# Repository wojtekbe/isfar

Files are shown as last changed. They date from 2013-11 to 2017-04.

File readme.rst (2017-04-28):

Isfar - a Hybrid-ROV underwater robot
=====================================

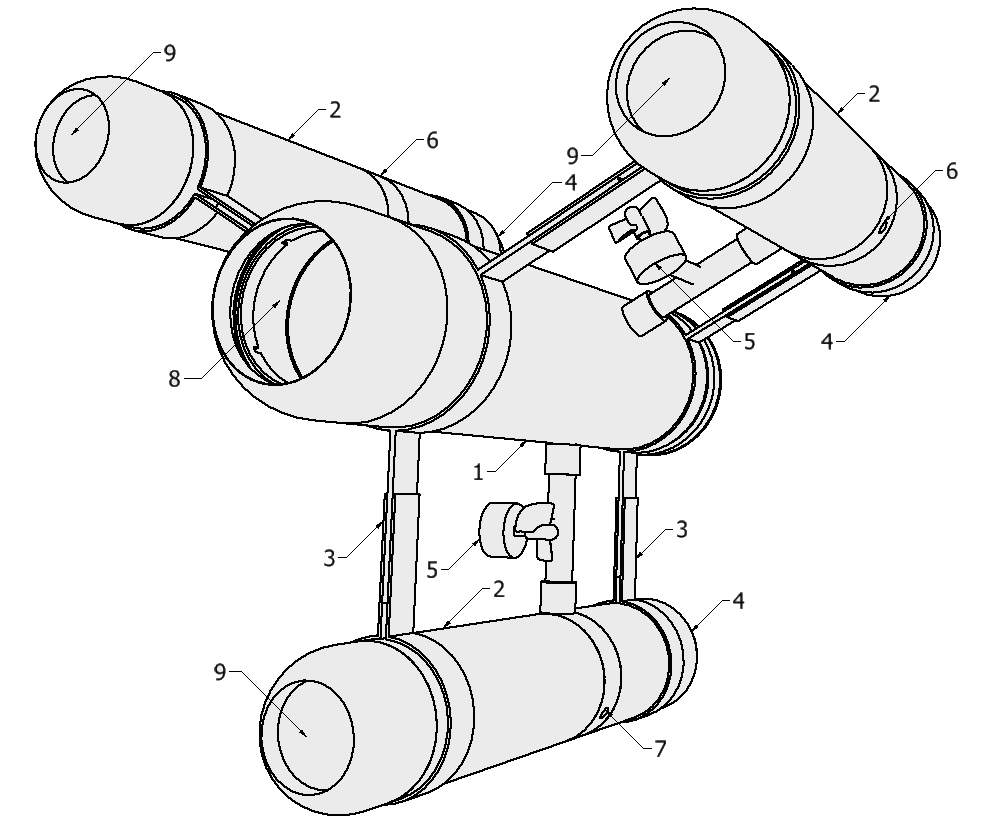
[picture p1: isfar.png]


+---+-------------+---+--------------------+---+----------------------------------+
| 1 | main hull   | 4 | main drive         | 7 | environmnental measurements unit |
+---+-------------+---+--------------------+---+----------------------------------+
| 2 | side hull   | 5 | maneouvering drive | 8 | onboard vision system            |
+---+-------------+---+--------------------+---+----------------------------------+
| 3 | steel frame | 6 | buoyancy drive     | 9 | LED lighting                     |
+---+-------------+---+--------------------+---+----------------------------------+

Boards: mainboard
-----------------

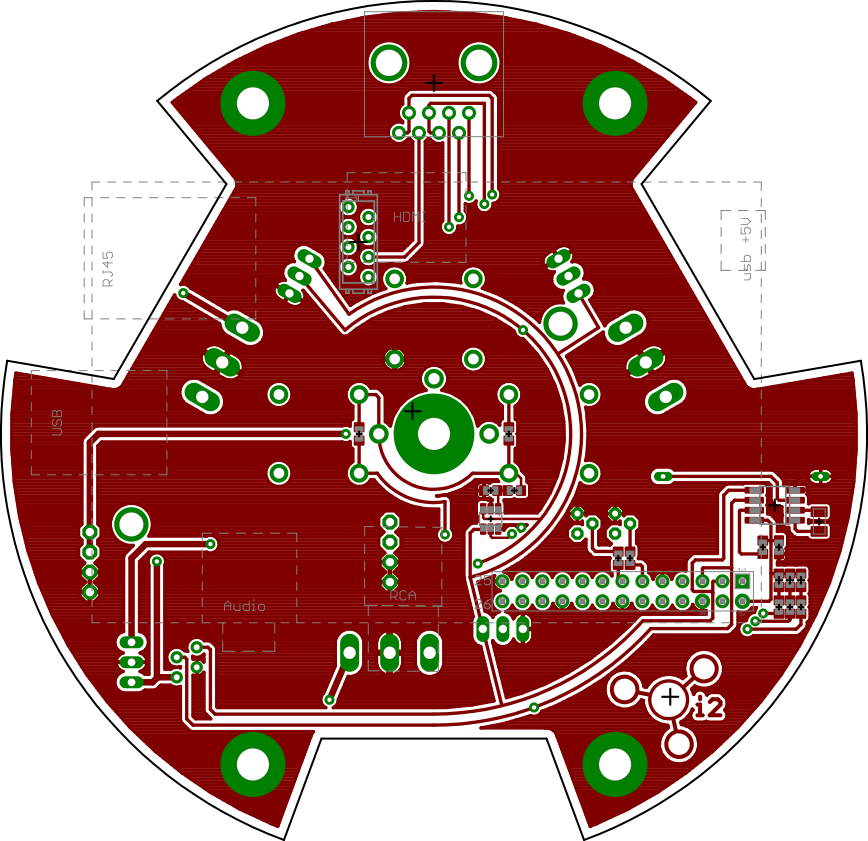
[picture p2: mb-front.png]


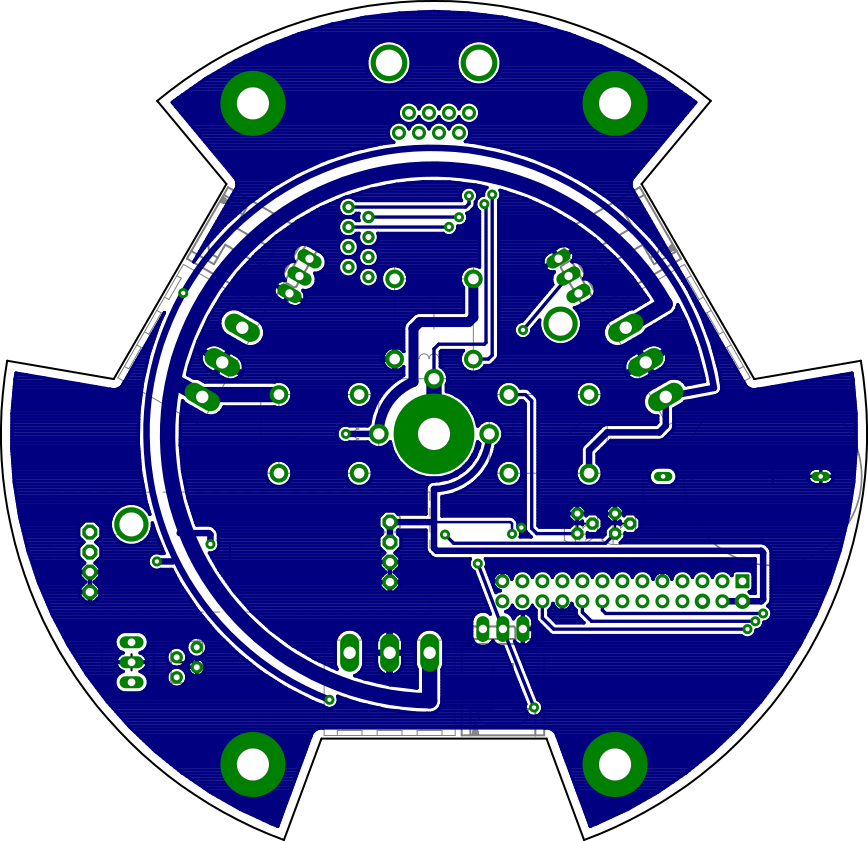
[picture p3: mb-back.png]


Boards: sidedriver
------------------

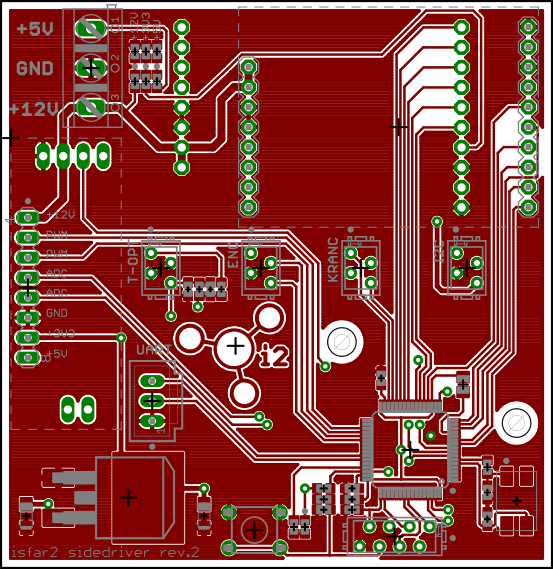
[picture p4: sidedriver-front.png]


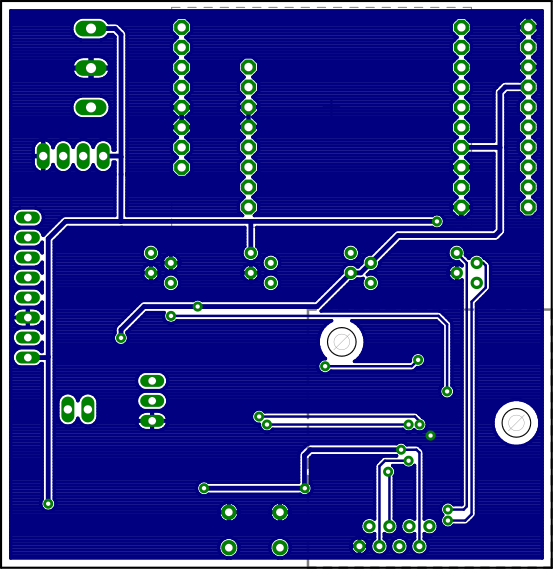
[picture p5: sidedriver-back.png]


Boards: trinocular/rpicam
-------------------------

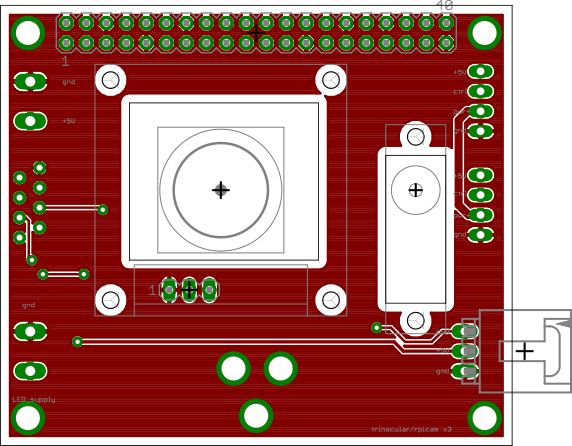
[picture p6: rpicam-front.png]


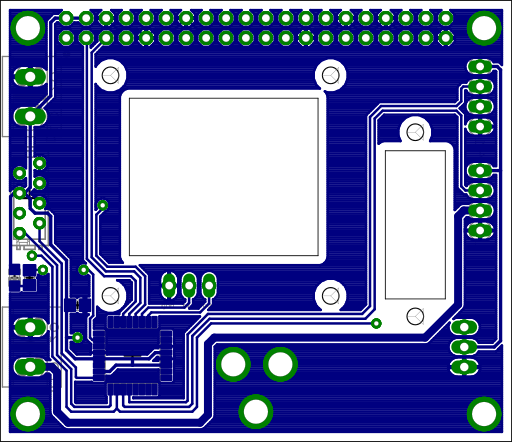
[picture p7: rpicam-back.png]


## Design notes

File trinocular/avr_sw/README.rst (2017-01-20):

SERVO:
the default i2c address is 0x0a, the angle reg is 0x01, the board is connected to i2c1 so

 .. code:: bash

 i2cset -y 1 0x0a 0x01 <angle>

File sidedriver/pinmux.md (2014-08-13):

Motor driver
====
| Name | Pin  |  Func. |
| --- | ---- | --- |
| M1_ENA  | PC3  | |
| M1_ENB  | PA3  | |
| M1_INA  | PC2  | |
| M1_INB  | PA4  | |
| M1_PWM  | PA1  | TIM2_CH2  |
| M1_CS | PA2  | ADCx_IN2  |
| ENC1 | PC6  | TIM8_CH1  |
| ENC2 | PC7  | TIM8_CH2  |

TIM4 -> calculate speed isr 
TIM5 -> PID isr

Tank driver
====
| Name | Pin  |  Func. |
| --- | ---- | --- |
| M2_ENA  | PB1  | |
| M2_ENB  | PA6  | |
| M2_INA  | PB2  | |
| M2_INB  | PA5  | |
| M2_PWM  | PB0  | TIM1_CH2N |
| M2_CS | PA7  | ADCx_IN7  |
| TRANS	  | PB6  | TIM3_CH3* |
| MIN | PB10 | |
| MAX | PB11 | |

* counting in isr

LED driver
====
| Name | Pin  |  Func. |
| --- | ---- | --- |
| LED_PWM | PC9  | TIM3_CH4  |
| SM1_PWM | PA0  | TIM5_CH1  |
| SM2_PWM | PA1  | TIM5_CH2  |

External IO
===
| Name | Pin  |  Func. |
| --- | ---- | --- |
| G_ADC1  | PC0  | ADC3_IN10 |
| G_ADC2  | PC1  | ADCx_IN11 |

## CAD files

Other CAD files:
mainb/i2-mainb-dim.dwg

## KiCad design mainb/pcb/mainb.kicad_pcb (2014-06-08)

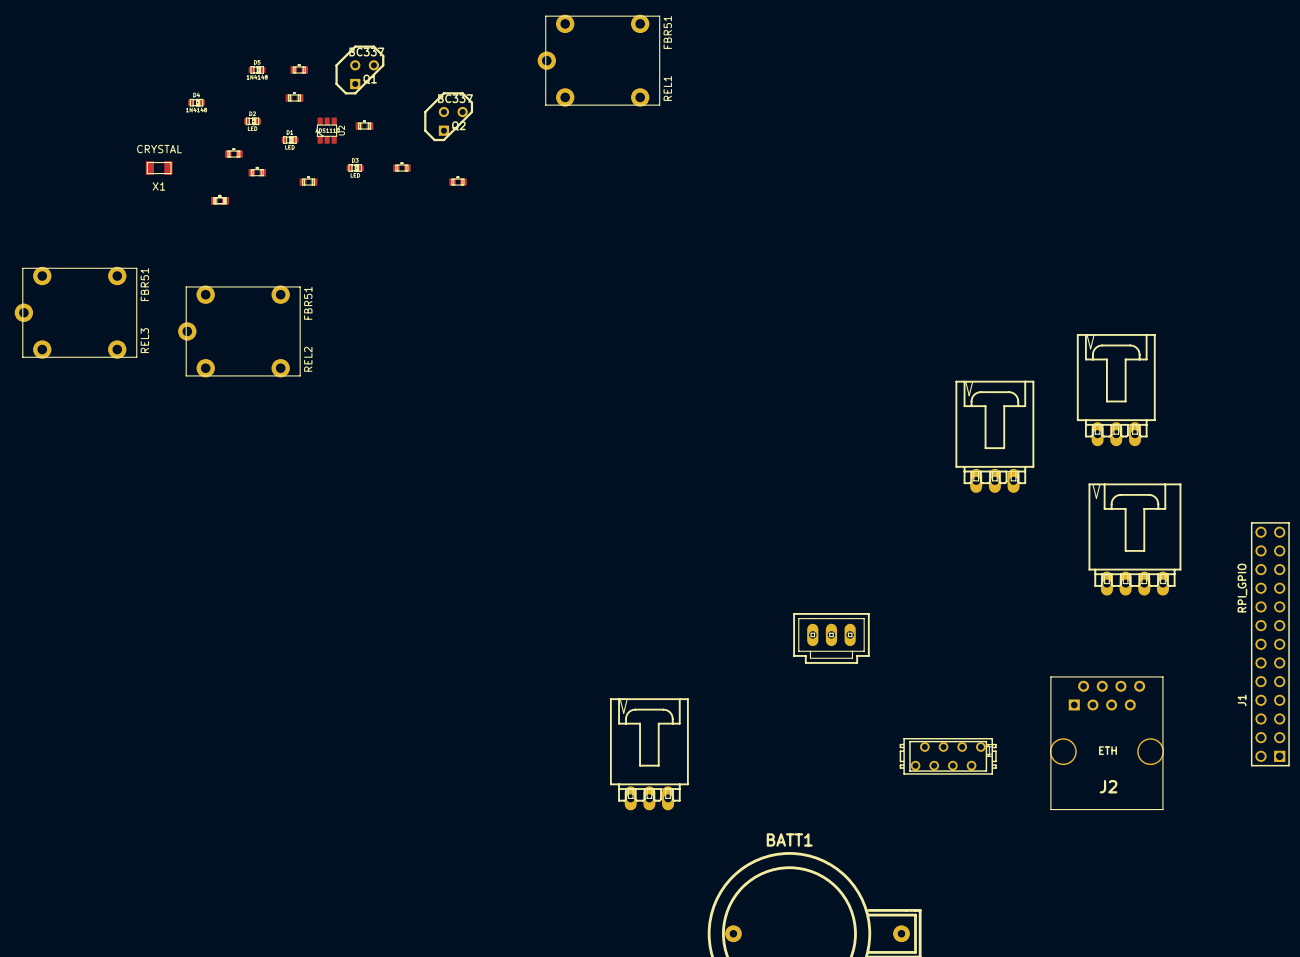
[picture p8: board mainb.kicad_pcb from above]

Board: 2 copper layers, 31 parts (0 on the bottom side), 27 nets, no tracks yet.

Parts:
BATT1: CR2303; CR2032H
C1, C2: 100n; c_0603
D1, D2, D3: LED; LED-0603
D4, D5: 1N4148; LED-0603
ETH->RPI1: CONN_8; con-amp-micromatch-MICROMATCH-8
J1: RPI_GPIO; pin_array_13x2
J2: ETH; RJ45_8
J3: I2C; WZ04R
J4, J5, J6: I2C; WZ03R
J11: UART; WZ03S
Q1, Q2: BC337; TO92-CBE
R1, R2, R6: ??; c_0603
R4, R5: R; c_0603
R7, R8, R9: 500; c_0603
REL1, REL2, REL3: FBR51
U2: ADS1110; SOT23_6
X1: CRYSTAL; CFPX-217

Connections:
+5C: J3.4, REL1.3
+5V: C1.2, C2.1, D4.2, J1.2, J1.4, R6.1, REL1.1, REL1.2, U2.5
+12V: R1.1, REL2.3
/+3V3: J1.1, R7.2, R8.2, R9.2
/LED1: D1.2, J1.22
/LED2: D2.2, J1.18
/LED3: D3.2, J1.16
/RX: J1.10, J11.2
/RX+: ETH->RPI1.4, J2.3
/RX-: ETH->RPI1.6, J2.6
/TX: J1.8, J11.3
/TX+: ETH->RPI1.1, J2.1
/TX-: ETH->RPI1.3, J2.2
AKU+: REL3.1, REL3.2
unnamed: D5.1, REL2.5
unnamed: D4.1, REL1.5
unnamed: R1.2, R2.1, U2.1
unnamed: D1.1, R9.1
unnamed: D2.1, R8.1
unnamed: D3.1, R7.1
unnamed: D5.2, REL2.1, REL2.2, REL3.3
PoE+: J2.4, J2.5, REL3.5
PoE-: BATT1.2, C1.1, C2.2, J1.6, J1.9, J1.14, J1.20, J1.25, J2.7, J2.8, J3.3, J4.3, J5.3, J6.3, J11.1, R2.2, U2.2, U2.6
REL#1: J1.11, R5.1
REL#2: J1.13, R4.1
SCL: J1.5, J3.2, J4.2, J5.2, J6.2, U2.3
SDA: J1.3, J3.1, J4.1, J5.1, J6.1, U2.4

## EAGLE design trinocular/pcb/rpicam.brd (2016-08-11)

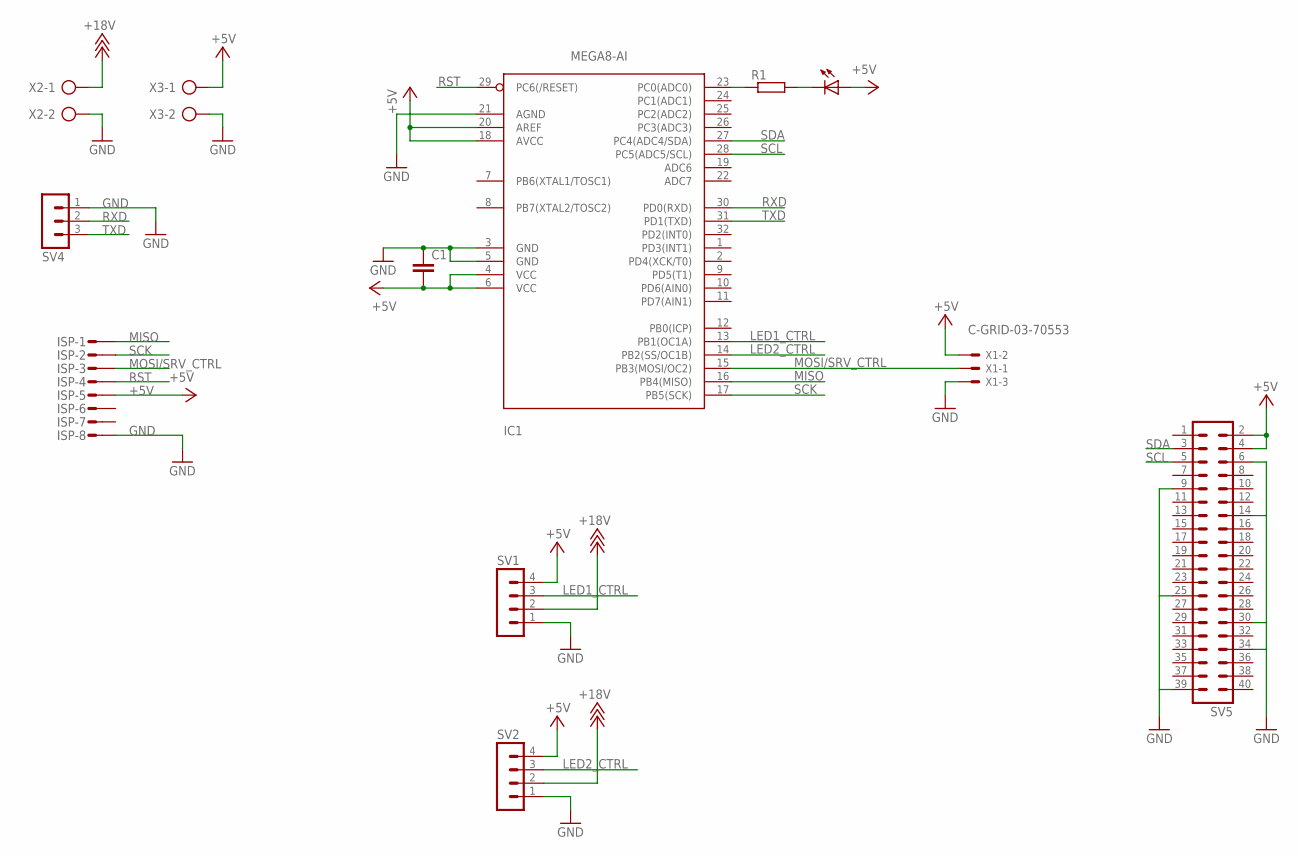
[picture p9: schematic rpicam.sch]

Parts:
C1: C-EUC0805; C0805
IC1: MEGA8-AI; TQFP32-08
ISP: MICROMATCH-8
LED1: LEDCHIP-LED0805; CHIP-LED0805
R1: R-EU_R0805; R0805
SV1, SV2: MA04-1
SV4: MA03-1
SV5: MA20-2
X1: C-GRID-03-70553; 70553-03
X2, X3: AK500/2

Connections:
+5V: C1.2, IC1.4 (VCC), IC1.6 (VCC), IC1.18 (AVCC), IC1.20 (AREF), ISP.5, LED1.A, SV1.4, SV2.4, SV5.2, SV5.4, X1.2, X3.1
+18V: SV1.2, SV2.2, X2.1
GND: C1.1, IC1.3 (GND), IC1.5 (GND), IC1.21 (AGND), ISP.8, SV1.1, SV2.1, SV4.1, SV5.6, SV5.9, SV5.14, SV5.25, SV5.30, SV5.34, SV5.39, X1.3, X2.2, X3.2
LED1_CTRL: IC1.13 (PB1(OC1A)), SV1.3
LED2_CTRL: IC1.14 (PB2(SS/OC1B)), SV2.3
MISO: IC1.16 (PB4(MISO)), ISP.1
MOSI/SRV_CTRL: IC1.15 (PB3(MOSI/OC2)), ISP.3, X1.1
unnamed: LED1.C, R1.2
unnamed: IC1.23 (PC0(ADC0)), R1.1
RST: IC1.29 (PC6(/RESET)), ISP.4
RXD: IC1.30 (PD0(RXD)), SV4.2
SCK: IC1.17 (PB5(SCK)), ISP.2
SCL: IC1.28 (PC5(ADC5/SCL)), SV5.5
SDA: IC1.27 (PC4(ADC4/SDA)), SV5.3
TXD: IC1.31 (PD1(TXD)), SV4.3

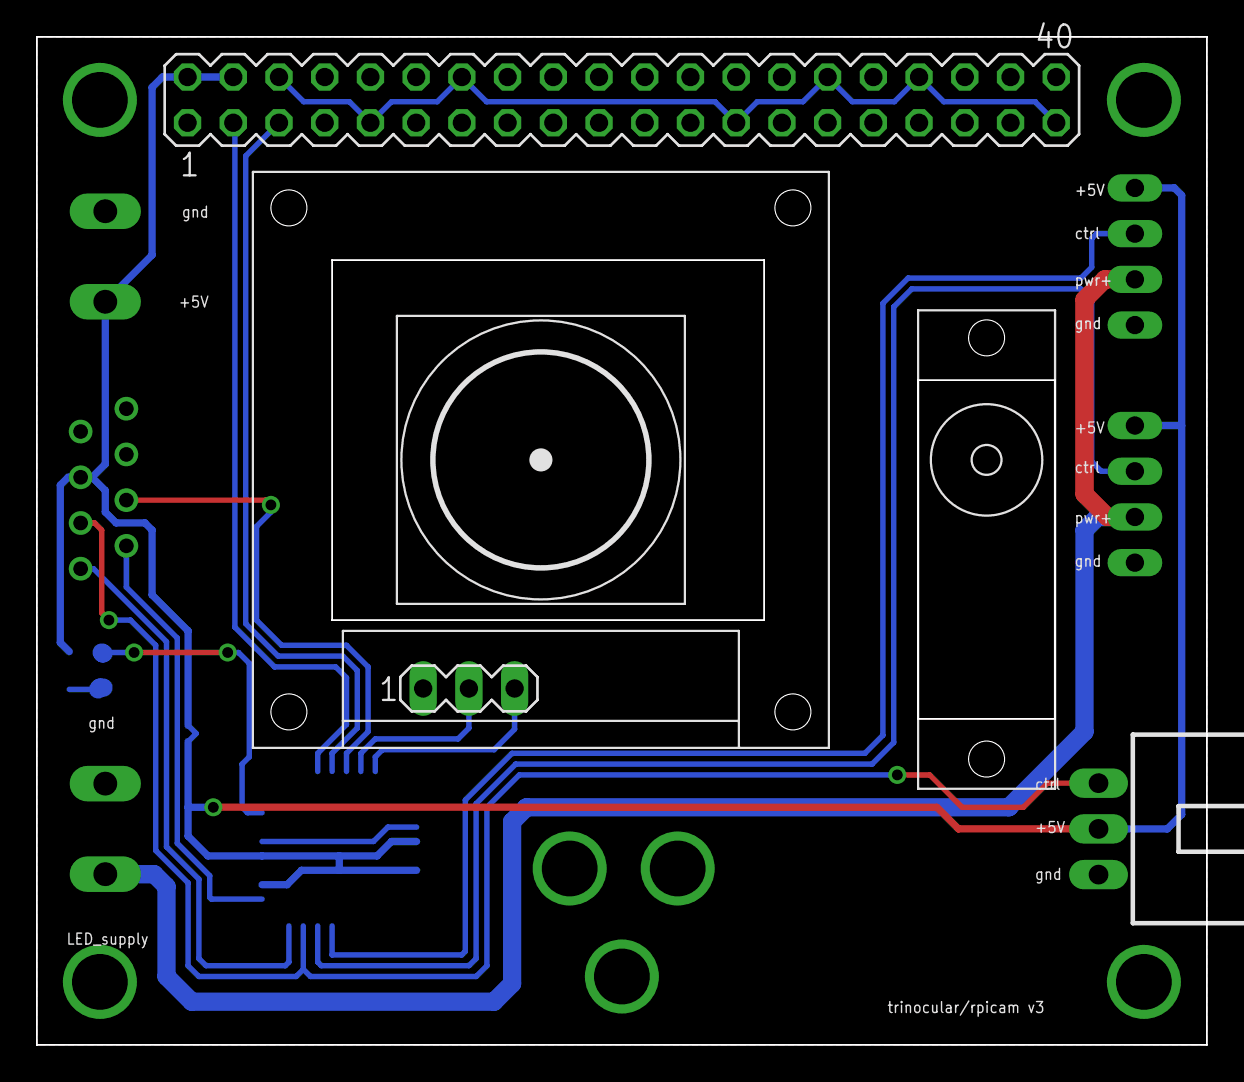
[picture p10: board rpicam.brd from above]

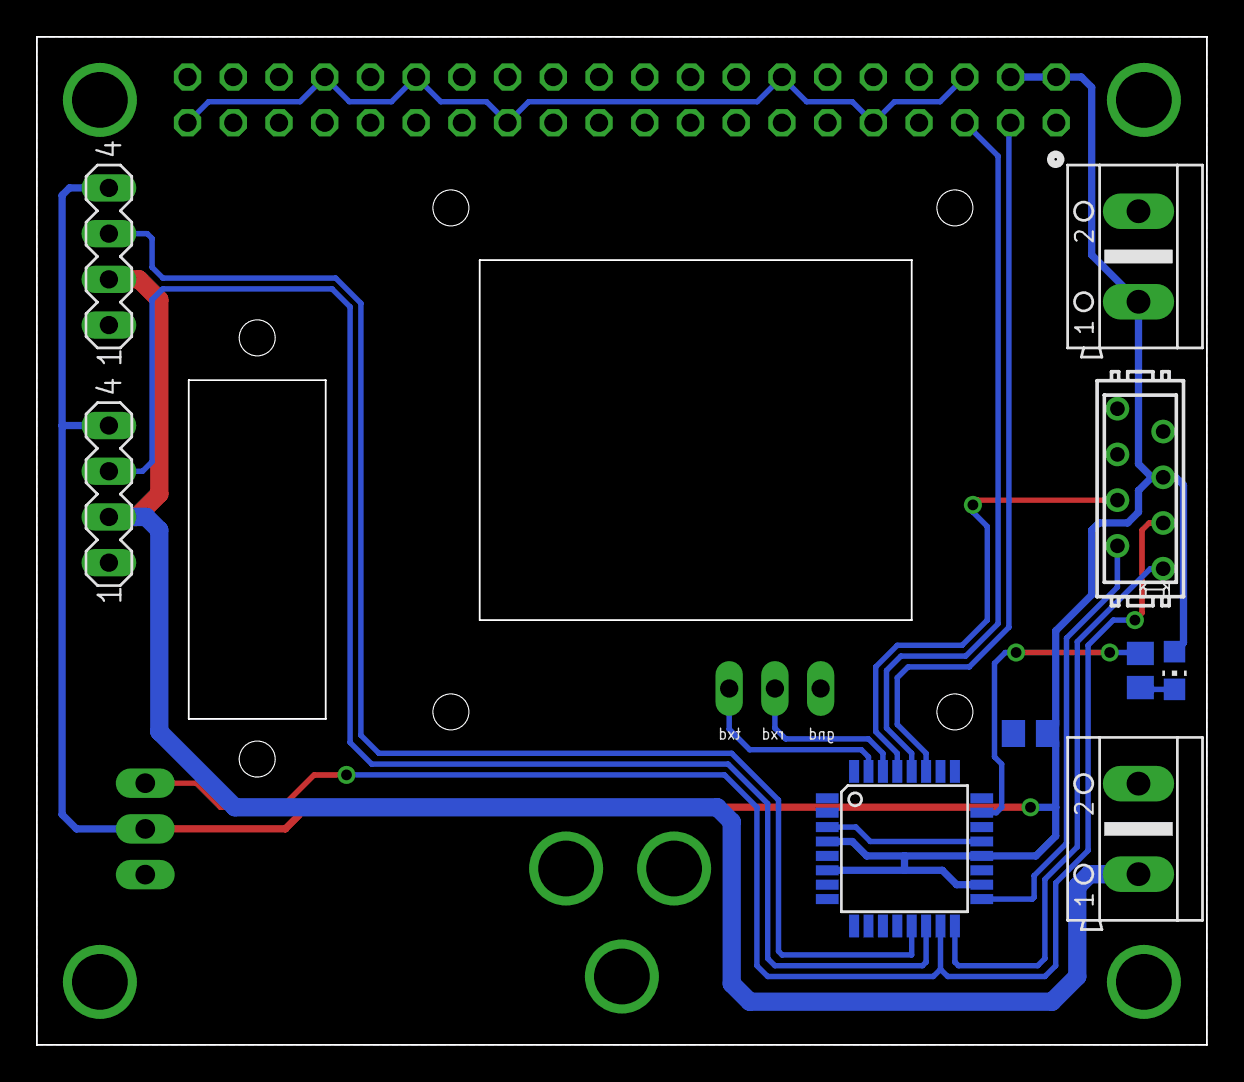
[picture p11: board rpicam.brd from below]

Board: 2 copper layers, 65.0 x 56.0 mm, 14 parts (9 on the bottom side), 15 nets.

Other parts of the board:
U$3: HS-35HD
U$4: RPICAM_WAVESHARE

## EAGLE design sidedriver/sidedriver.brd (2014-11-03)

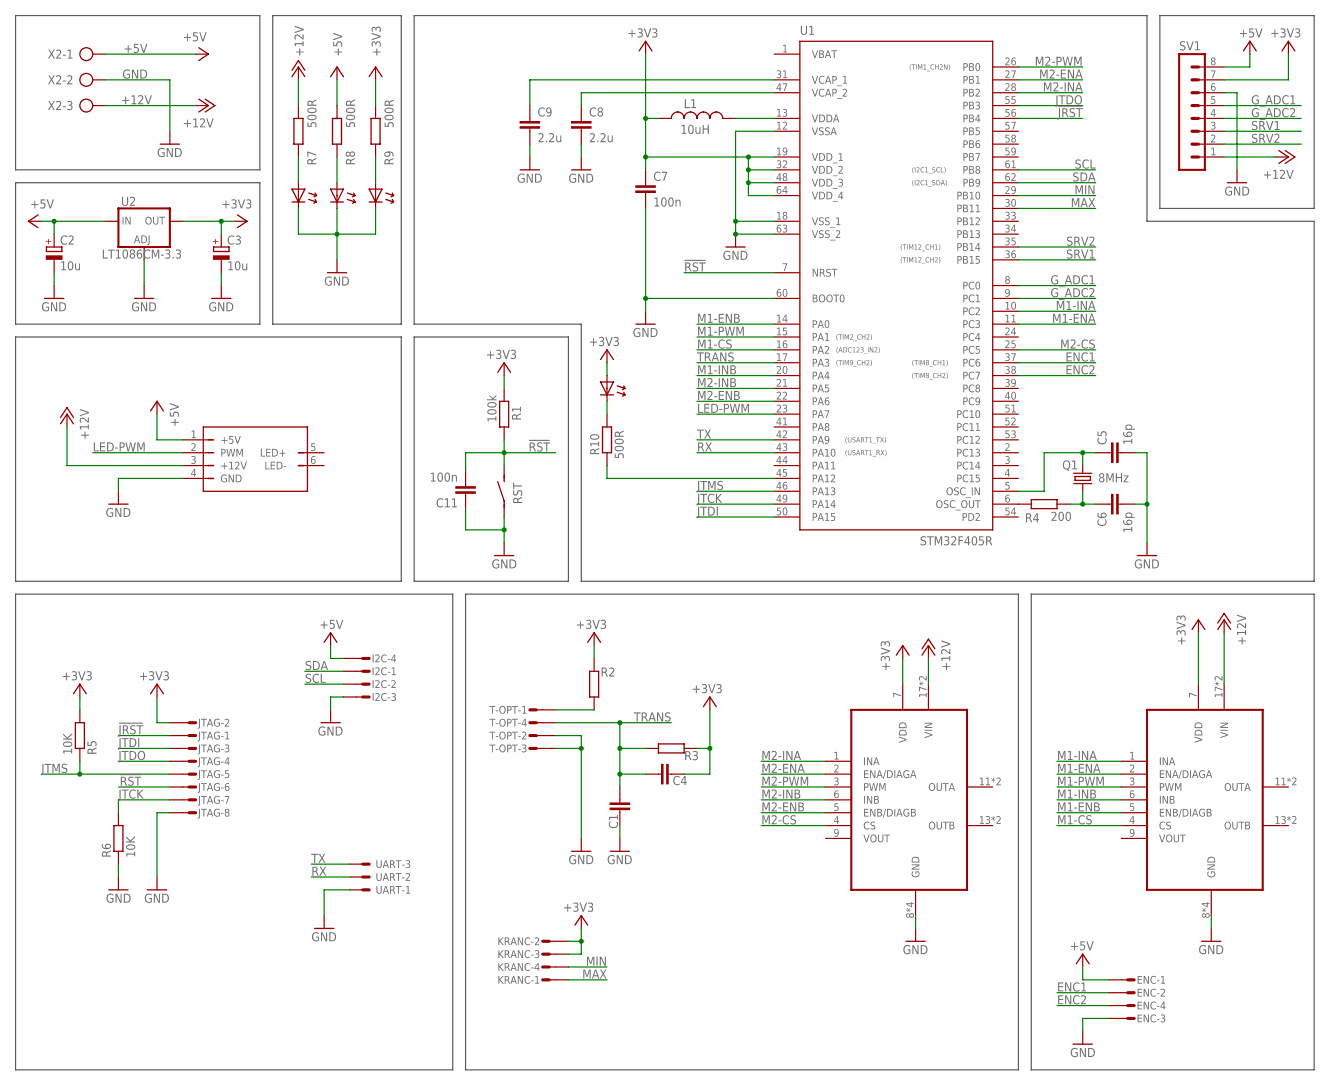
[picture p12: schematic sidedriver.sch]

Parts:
C1, C4: C-EUC0603; C0603
C2, C3: 10u; SMC_A
C5, C6: 16p; C0603
C7, C11: 100n; C0603
C8, C9: 2.2u; C0603
ENC: MICROMATCH-4
I2C: MICROMATCH-4
JTAG: MICROMATCH-8
KRANC: MICROMATCH-4
L1: 10uH; L0805
Q1: 8MHz; 12SMX
R1: 100k; R0603
R2, R3: R-EU_R0603; R0603
R4: 200; R0603
R5, R6: 10K; R0603
R7, R8, R9, R10: 500R; R0603
RST: TACT_SWITCH; SWITCH
SV1: MA08-1
T-OPT: MICROMATCH-4
U1: STM32F405R; TQFP64
U2: LT1086CM-3.3; D2PACK
U$2: LEDD1
U$3, U$4: POLOLU-1451
U$6, U$7, U$8, U$9: LED0603; D0603
UART: C-GRID-03-70543; 70543-03
X2: AK500/3

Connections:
!JRST: JTAG.1, U1.56 (PB4)
!RST: C11.2, JTAG.6, R1.2, RST.2 (S), RST.4 (S), U1.7 (NRST)
+3V3: C3.+, C4.1, C7.1, JTAG.2, KRANC.2, KRANC.3, L1.1, R1.1, R2.1, R3.1, R5.2, R9.1, SV1.7, U1.19 (VDD_1), U1.32 (VDD_2), U1.48 (VDD_3), U1.64 (VDD_4), U2.2 (OUT), U$3.7 (VDD), U$4.7 (VDD), U$9.1 (A)
+5V: C2.+, ENC.1, I2C.4, R8.1, SV1.8, U2.3 (IN), U$2.1 (+5V), X2.1
+12V: R7.1, SV1.1, U$2.3 (+12V), U$3.17 (VIN), U$3.18 (VIN), U$4.17 (VIN), U$4.18 (VIN), X2.3
ENC1: ENC.2, U1.37 (PC6)
ENC2: ENC.4, U1.38 (PC7)
GND: C1.1, C2.-, C3.-, C5.2, C6.2, C7.2, C8.2, C9.2, C11.1, ENC.3, I2C.3, JTAG.8, R6.1, RST.1, RST.3, SV1.6, T-OPT.2, T-OPT.3, U1.12 (VSSA), U1.18 (VSS_1), U1.60 (BOOT0), U1.63 (VSS_2), U2.1 (ADJ), U$2.4 (GND), U$3.8 (GND), U$3.10 (GND), U$3.15 (GND), U$3.16 (GND), U$4.8 (GND), U$4.10 (GND), U$4.15 (GND), U$4.16 (GND), U$6.2 (C), U$7.2 (C), U$8.2 (C), UART.1, X2.2
G_ADC1: SV1.5, U1.8 (PC0)
G_ADC2: SV1.4, U1.9 (PC1)
JTCK: JTAG.7, R6.2, U1.49 (PA14)
JTDI: JTAG.3, U1.50 (PA15)
JTDO: JTAG.4, U1.55 (PB3)
JTMS: JTAG.5, R5.1, U1.46 (PA13)
LED-PWM: U1.23 (PA7), U$2.2 (PWM)
M1-CS: U1.16 (PA2), U$4.4 (CS)
M1-ENA: U1.11 (PC3), U$4.2 (ENA/DIAGA)
M1-ENB: U1.14 (PA0), U$4.5 (ENB/DIAGB)
M1-INA: U1.10 (PC2), U$4.1 (INA)
M1-INB: U1.20 (PA4), U$4.6 (INB)
M1-PWM: U1.15 (PA1), U$4.3 (PWM)
M2-CS: U1.25 (PC5), U$3.4 (CS)
M2-ENA: U1.27 (PB1), U$3.2 (ENA/DIAGA)
M2-ENB: U1.22 (PA6), U$3.5 (ENB/DIAGB)
M2-INA: U1.28 (PB2), U$3.1 (INA)
M2-INB: U1.21 (PA5), U$3.6 (INB)
M2-PWM: U1.26 (PB0), U$3.3 (PWM)
MAX: KRANC.1, U1.30 (PB11)
MIN: KRANC.4, U1.29 (PB10)
unnamed: R2.2, T-OPT.1
unnamed: C6.1, Q1.1, R4.2
unnamed: C5.1, Q1.3 (2), U1.5 (OSC_IN)
unnamed: R7.2, U$6.1 (A)
unnamed: R8.2, U$7.1 (A)
unnamed: R9.2, U$8.1 (A)
unnamed: R10.2, U$9.2 (C)
unnamed: R10.1, U1.45 (PA12)
unnamed: L1.2, U1.13 (VDDA)
unnamed: R4.1, U1.6 (OSC_OUT)
unnamed: C8.1, U1.47 (VCAP_2)
unnamed: C9.1, U1.31 (VCAP_1)
RX: U1.43 (PA10), UART.2
SCL: I2C.2, U1.61 (PB8)
SDA: I2C.1, U1.62 (PB9)
SRV1: SV1.3, U1.36 (PB15)
SRV2: SV1.2, U1.35 (PB14)
TRANS: C1.2, C4.2, R3.2, T-OPT.4, U1.17 (PA3)
TX: U1.42 (PA9), UART.3

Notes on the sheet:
(ADC123_IN2)
(TIM1_CH2N)
(TIM2_CH2)
(TIM8_CH1)
(TIM8_CH2)
(I2C1_SDA)
(I2C1_SCL)
(USART1_TX)
(USART1_RX)
(TIM12_CH1)
(TIM12_CH2)
(TIM9_CH2)

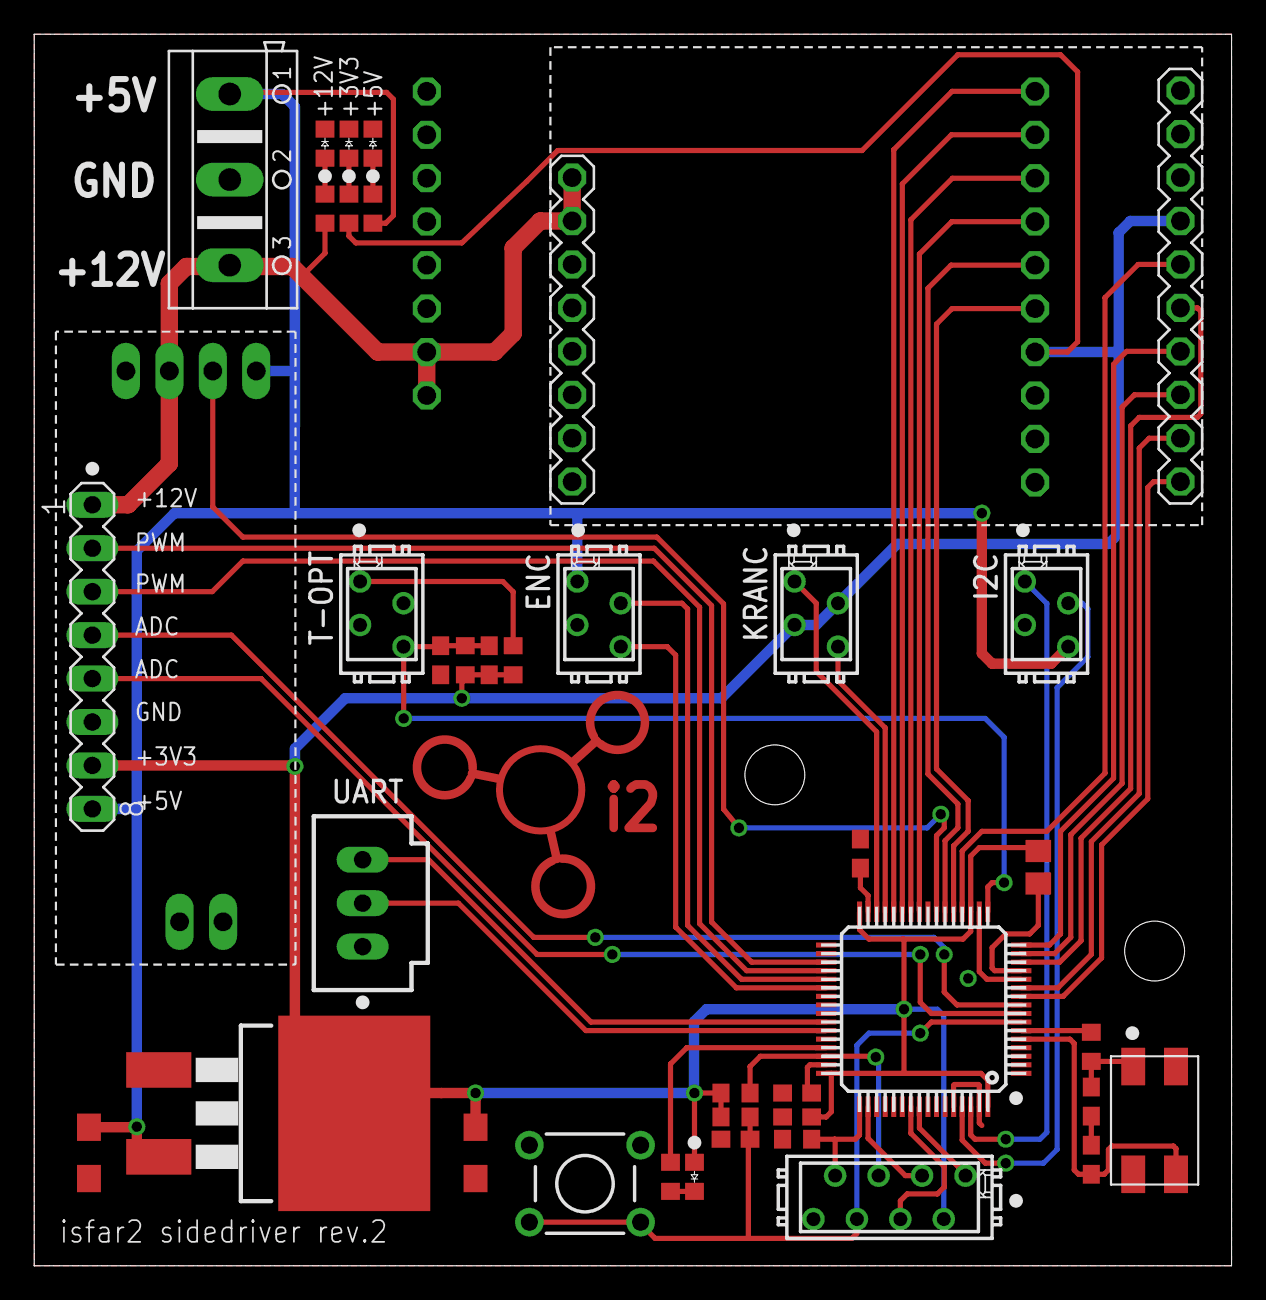
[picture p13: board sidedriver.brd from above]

Board: 2 copper layers, 70.0 x 72.0 mm, 41 parts (1 on the bottom side), 48 nets.

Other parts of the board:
U$5: I2-LOGO

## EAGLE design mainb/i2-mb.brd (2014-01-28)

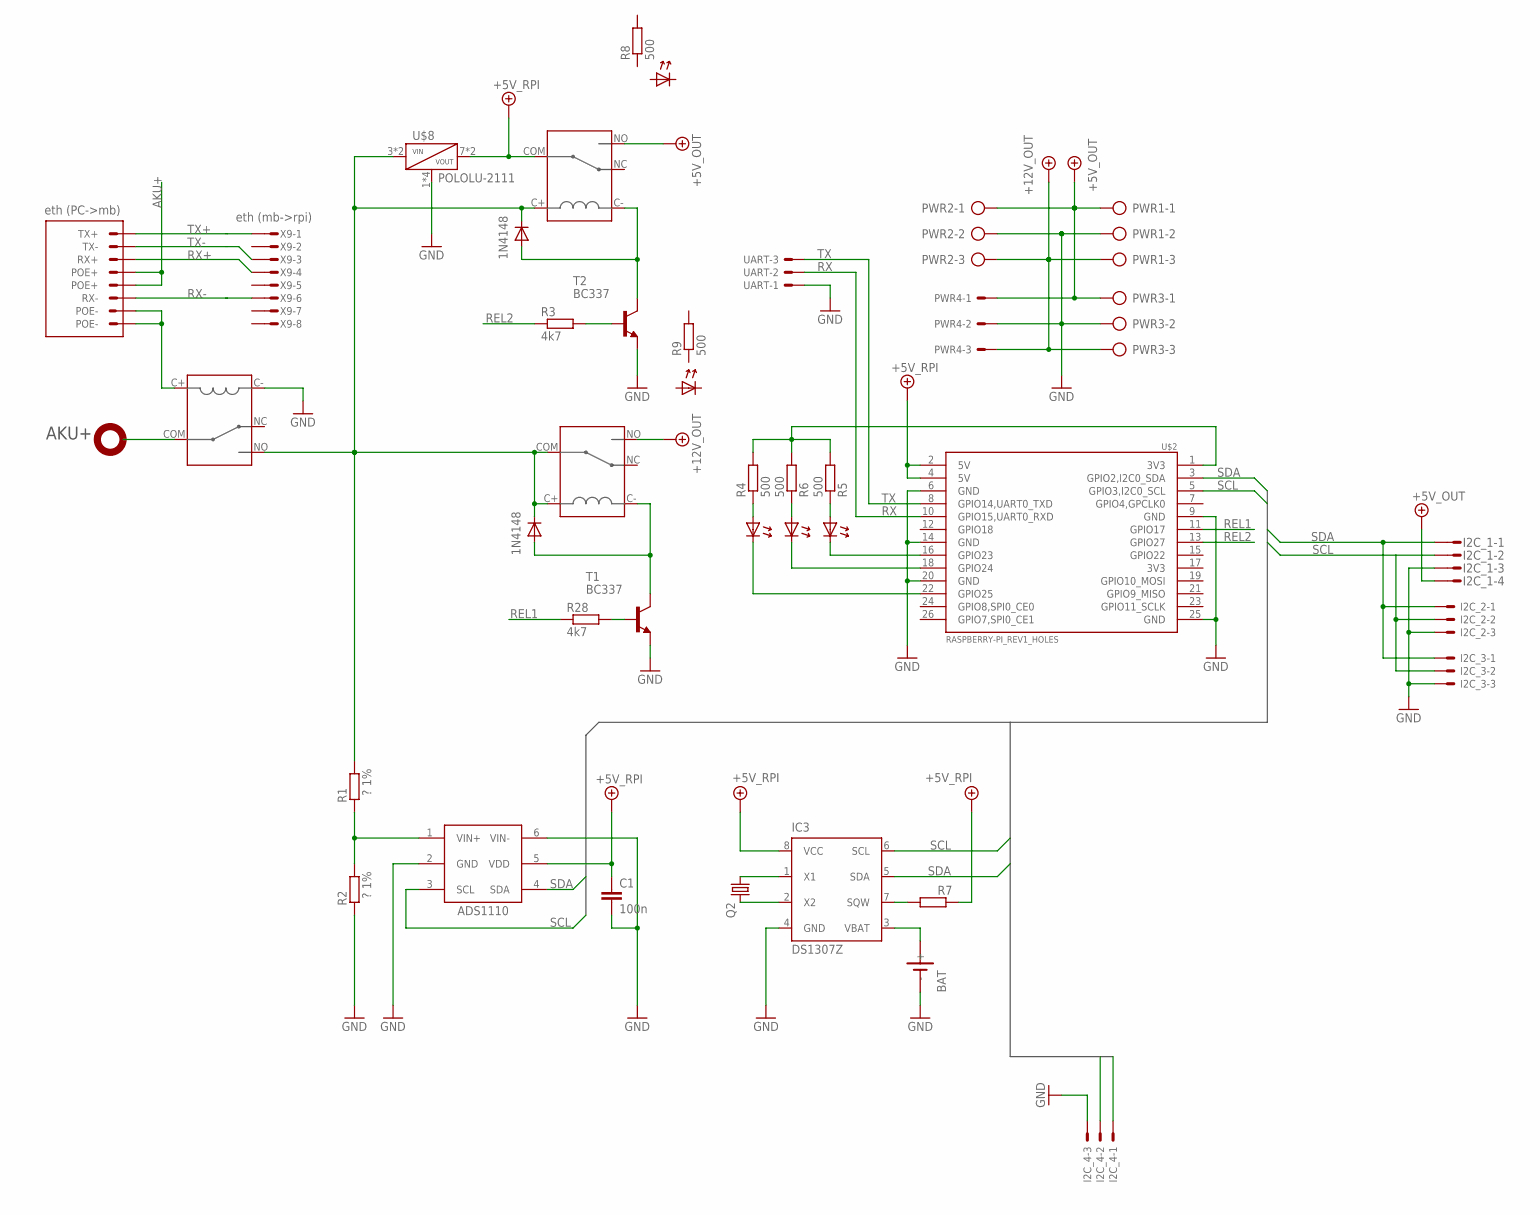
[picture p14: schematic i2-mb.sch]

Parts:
BAT: SN2032
C1: 100n; C0603
I2C_1: MICROMATCH-4
I2C_2, I2C_3, I2C_4: C-GRID-03-70553; 70553-03
IC1: ADS1110; SOT-23-6
IC3: DS1307Z; SOIC8
LED1, LED2, LED3, LED4, LED5: LED0603; D0603
PWR1, PWR2, PWR3: TBMP5103RC-KFV1; TBMP5103RC-KF
PWR4: C-GRID-03-70543; 70543-03
Q2: CRYSTAL; CFPX-217
R1, R2: ? 1%; R0603
R3, R28: 4k7; R0603
R4, R5, R6, R8, R9: 500; R0603
R7: R-EU_R0603; R0603
T1, T2: BC337; TO92
U$2: RASPBERRY-PI_REV1_HOLES; RASPBERRY-PI_HOLES
U$3, U$4: 1N4148; D0603
U$5, U$6, U$7: FBR51; PC_RELAY
U$8: POLOLU-2111
UART: C-GRID-03-70543; 70543-03
X9: eth (mb->rpi); MICROMATCH-8
X_ETH: eth (PC->mb); 8P8C-TOP

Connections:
+5V: I2C_1.4, PWR1.1, PWR2.1, PWR3.1, PWR4.1, U$5.NO
+5V_RPI: C1.1, IC1.5 (VDD), IC3.8 (VCC), R7.1, U$2.2 (5V), U$2.4 (5V), U$5.COM, U$8.7 (VOUT), U$8.8 (VOUT)
+12V_IN: R1.1, U$3.2 (C), U$4.2 (C), U$5.C+, U$6.NO, U$7.C+, U$7.COM, U$8.3 (VIN), U$8.4 (VIN)
+12V_OUT: PWR1.3, PWR2.3, PWR3.3, PWR4.3, U$7.NO
AKU+: U$6.COM, X_ETH.4 (POE+), X_ETH.5 (POE+)
GND: BAT.-, C1.2, I2C_1.3, I2C_2.3, I2C_3.3, I2C_4.3, IC1.2 (GND), IC1.6 (VIN-), IC3.4 (GND), PWR1.2, PWR2.2, PWR3.2, PWR4.2, R2.2, T1.1 (E), T2.1 (E), U$2.6 (GND), U$2.9 (GND), U$2.14 (GND), U$2.20 (GND), U$2.25 (GND), U$6.C-, U$8.1 (GND), U$8.2 (GND), U$8.5 (GND), U$8.6 (GND), UART.1
LED2: LED2.2 (C), U$2.16 (GPIO23)
LED3: LED3.2 (C), U$2.18 (GPIO24)
unnamed: R3.2, T2.2 (B)
unnamed: T2.3 (C), U$3.1 (A), U$5.C-
unnamed: BAT.+, IC3.3 (VBAT)
unnamed: LED2.1 (A), R5.1
unnamed: LED1.1 (A), R4.1
unnamed: IC3.1 (X1), Q2.1
unnamed: LED1.2 (C), U$2.22 (GPIO25)
unnamed: LED3.1 (A), R6.1
unnamed: IC3.2 (X2), Q2.2
unnamed: IC3.7 (SQW), R7.2
unnamed: R4.2, R5.2, R6.2, U$2.1 (3V3)
unnamed: T1.3 (C), U$4.1 (A), U$7.C-
unnamed: R28.2, T1.2 (B)
POE-: U$6.C+, X_ETH.7 (POE-), X_ETH.8 (POE-)
REL1: R28.1, U$2.11 (GPIO17)
REL2: R3.1, U$2.13 (GPIO27)
RX: U$2.10 (GPIO15,UART0_RXD), UART.2
RX+: X9.4, X_ETH.3 (RX+)
RX-: X9.6, X_ETH.6 (RX-)
SCL: I2C_1.2, I2C_2.2, I2C_3.2, I2C_4.2, IC1.3 (SCL), IC3.6 (SCL), U$2.5 (GPIO3,I2C0_SCL)
SDA: I2C_1.1, I2C_2.1, I2C_3.1, I2C_4.1, IC1.4 (SDA), IC3.5 (SDA), U$2.3 (GPIO2,I2C0_SDA)
TX: U$2.8 (GPIO14,UART0_TXD), UART.3
TX+: X9.1, X_ETH.1 (TX+)
TX-: X9.3, X_ETH.2 (TX-)
V_SENS: IC1.1 (VIN+), R1.2, R2.1

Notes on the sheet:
AKU+

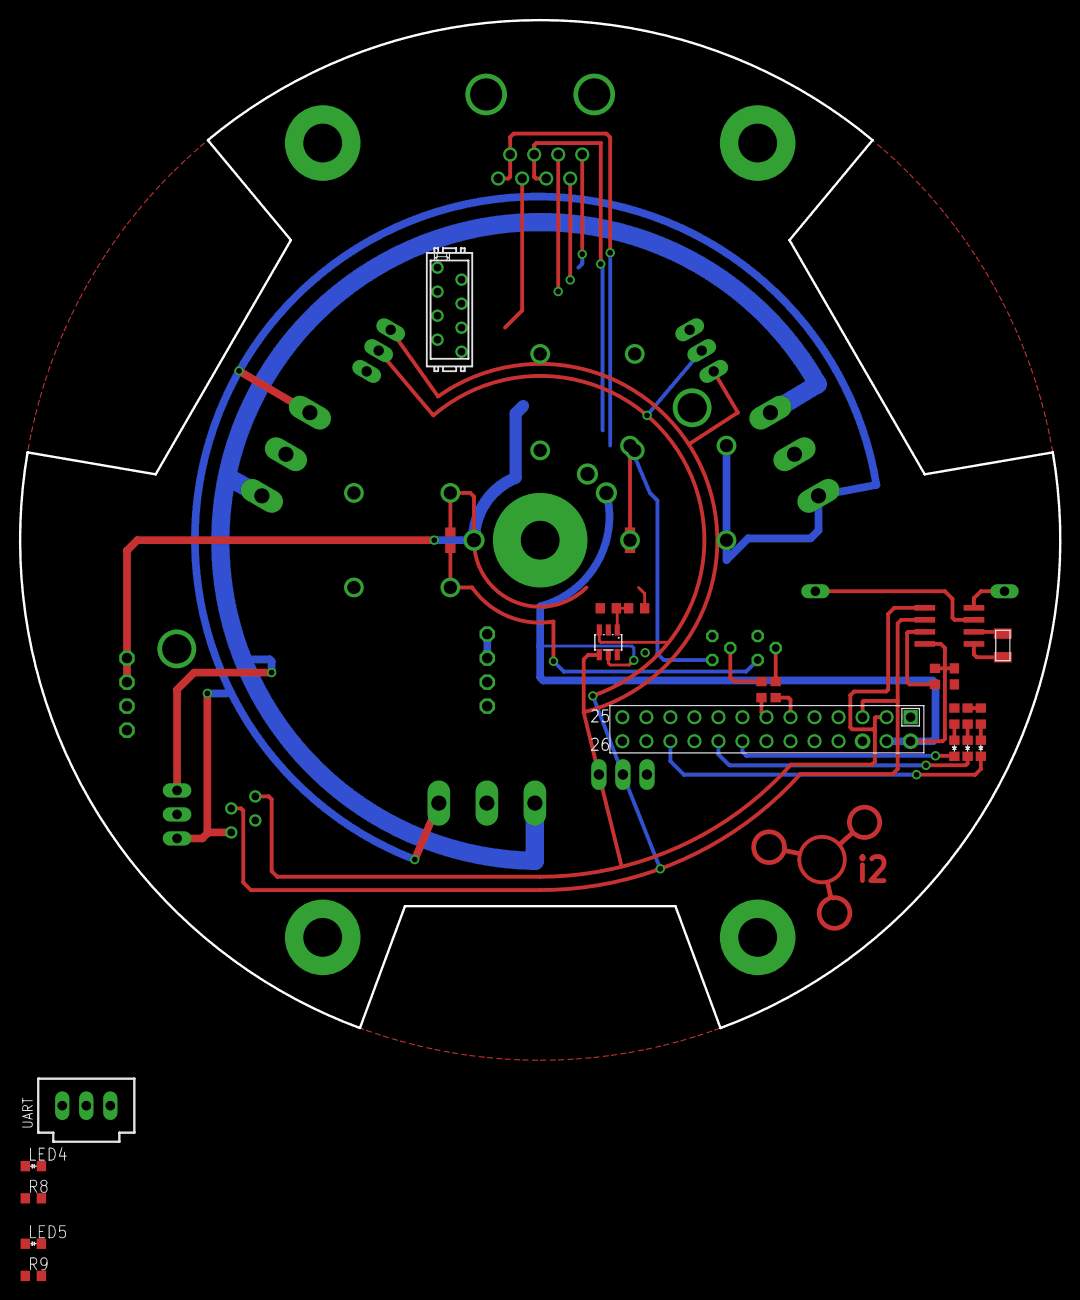
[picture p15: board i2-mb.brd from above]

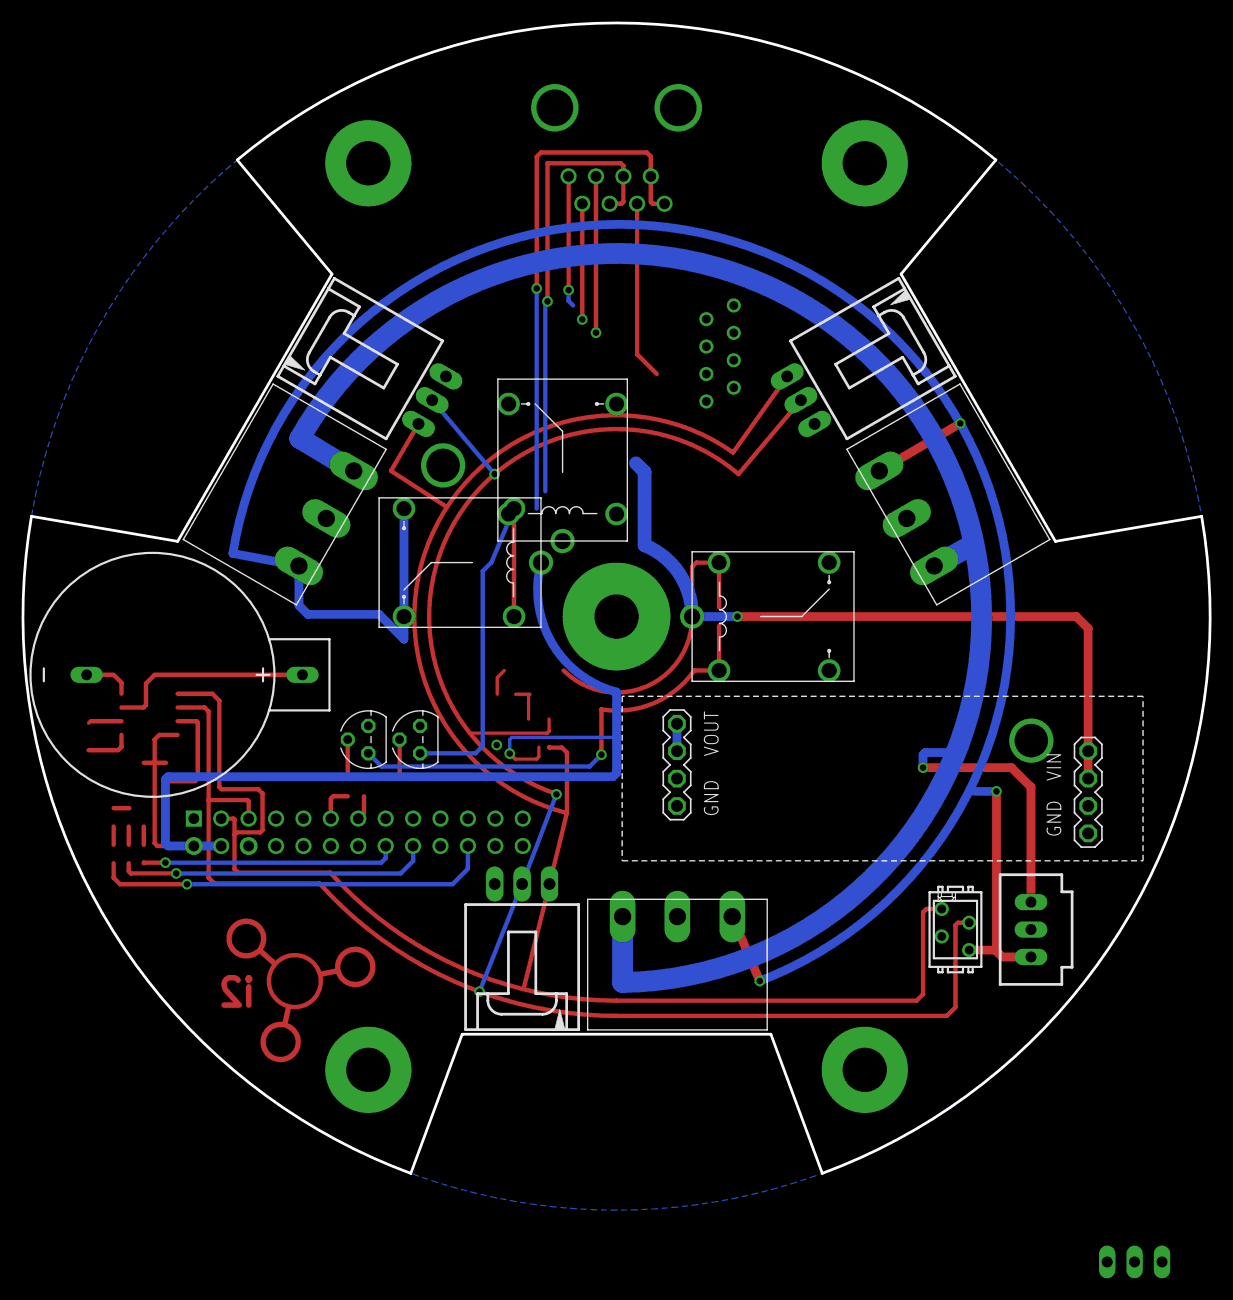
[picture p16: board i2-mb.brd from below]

Board: 2 copper layers, 110.0 x 106.6 mm, 41 parts (15 on the bottom side), 33 nets.

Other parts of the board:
U$1: I2-LOGO

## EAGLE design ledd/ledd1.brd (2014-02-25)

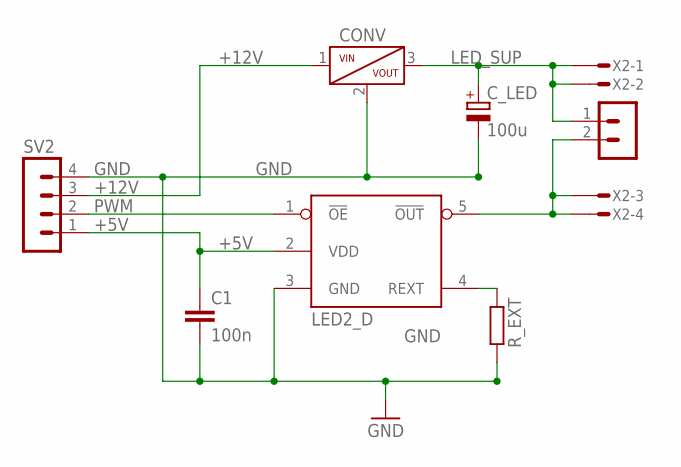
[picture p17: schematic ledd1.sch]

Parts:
C1: 100n; C0603
CONV: POLOLU-799
C_LED: 100u; E2-4
LED2_D: LED1_drv; TO-265
R_EXT: R-EU_R0603; R0603
SV2: MA04-1
SV3: MA02-1; MA03-1
X2: LEDOUT; MICROMATCH-4

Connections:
+5V: C1.1, LED2_D.2 (VDD), SV2.1
+12V: CONV.1 (VIN), SV2.3
GND: C1.2, CONV.2 (GND), C_LED.-, LED2_D.3 (GND), LED2_D.6 (GND), R_EXT.2, SV2.4
LED_SUP: CONV.3 (VOUT), C_LED.+, SV3.1, X2.1, X2.2
unnamed: LED2_D.4 (REXT), R_EXT.1
unnamed: LED2_D.5 (!OUT), SV3.2, X2.3, X2.4
PWM: LED2_D.1 (!OE), SV2.2

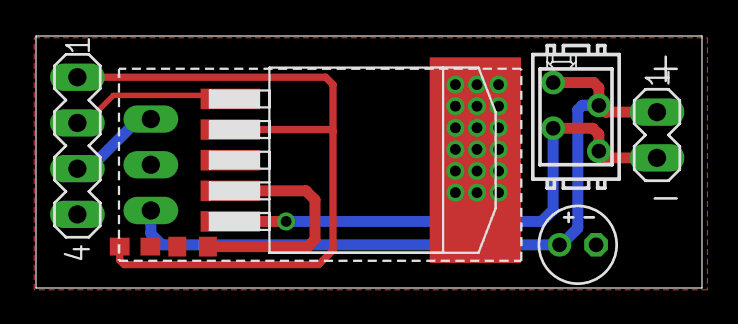
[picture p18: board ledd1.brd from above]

Board: 2 copper layers, 37.0 x 14.0 mm, 8 parts (0 on the bottom side), 7 nets.

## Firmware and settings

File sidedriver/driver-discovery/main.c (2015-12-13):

#include "stm32f4xx.h"
#include "stm32f4xx_usart.h"
#include "core_cm4.h"
#include "tinyprintf.h"
#include <unistd.h>

#define GREEN 12
#define ORANGE 13
#define RED 14
#define BLUE 15
#define LED(n,s) if(s) GPIOD->BSRRL |= (1 << n); else GPIOD->BSRRH |= (1 << n);
#define LEDT(n) GPIOD->ODR ^= (1<<n);

int _write(int, char*, int);
void init_leds(void);
void init_usart(void);
void putc(void*, char);
void init_timer4(void);
void init_timer3(void);
void init_i2c(void);
void wait(uint32_t);

uint16_t i2c_regs[4] = {0, 0, 0, 0};
int i2c_bytes_received;
int i2c_reg_idx;

void putc(void* p, char c)
{
	(void)p; /* suppress warning */
	while ((USART2->SR & USART_SR_TXE) == 0);
	USART2->DR = c;
}

void init_leds(void)
{
	// PD11-15 as outputs
	RCC->AHB1ENR |= RCC_AHB1ENR_GPIODEN;
	GPIOD->MODER |= GPIO_MODER_MODER11_0;
	GPIOD->MODER |= GPIO_MODER_MODER12_0;
	GPIOD->MODER |= GPIO_MODER_MODER13_0;
	GPIOD->MODER |= GPIO_MODER_MODER14_0;
	GPIOD->MODER |= GPIO_MODER_MODER15_0;
}

void init_usart(void)
{	
	USART_InitTypeDef USART_InitStructure;

	RCC->APB1ENR |= RCC_APB1ENR_USART2EN;
	RCC->AHB1ENR |= RCC_AHB1ENR_GPIOAEN;
	
	GPIOA->MODER |= GPIO_MODER_MODER2_1;
	//GPIOA->PUPDR |= GPIO_PUPDR_PUPDR2_0;
	GPIOA->AFR[0] |= 0x0000700;

	USART_InitStructure.USART_BaudRate = 115200;	
	USART_InitStructure.USART_WordLength = USART_WordLength_8b;
	USART_InitStructure.USART_StopBits = USART_StopBits_1;
	USART_InitStructure.USART_Parity = USART_Parity_No;
	USART_InitStructure.USART_HardwareFlowControl = USART_HardwareFlowControl_None;
	USART_InitStructure.USART_Mode = USART_Mode_Tx;
	USART_Init(USART2, &USART_InitStructure);
	USART_Cmd(USART2, ENABLE); // enable USART2
}

void init_timer4(void)
{
	RCC->AHB1ENR |= RCC_AHB1ENR_GPIODEN;
	RCC->APB1ENR |= RCC_APB1ENR_TIM4EN; 
	GPIOD->MODER |= GPIO_MODER_MODER13_1;
	GPIOD->AFR[1] |= (2 << 20);
	TIM4->PSC =   16799;
	TIM4->ARR =   99;
	TIM4->CCR2 =  50;
	TIM4->CCMR1 = TIM_CCMR1_OC2M_1 | TIM_CCMR1_OC2M_2; // Output Compare 2 Mode = 110 (PWM 1 Mode)
	TIM4->CCER |= TIM_CCER_CC2E; // Capture/Compare 2 output enable
	TIM4->CR1 |= 0 | TIM_CR1_CEN;
}

void init_timer3()
{
	// Capturing on PC6
	RCC->AHB1ENR |= RCC_AHB1ENR_GPIOCEN;
	RCC->APB1ENR |= RCC_APB1ENR_TIM3EN;
	GPIOC->MODER |= GPIO_MODER_MODER6_1; // AF for PC6
	GPIOC->AFR[0] |= (2 << 24); // AF2 for PC6
	TIM3->PSC = 10000-1;
	TIM3->ARR = 1000-1;
	TIM3->CCMR1 |= TIM_CCMR1_CC1S_0; // CC1 channel is conf. as INPUT, IC1 is mapped on TI1
	TIM3->CCER |= TIM_CCER_CC1E; 
	TIM3->CR1 |= TIM_CR1_CEN;
}

void init_i2c(void) 
{
	RCC->AHB1ENR |= RCC_AHB1ENR_GPIOBEN;
	RCC->APB1ENR |= RCC_APB1ENR_I2C1EN;
	GPIOB->OTYPER |= (1 << 7) | (1 << 8); // Open drain PB7,8
	GPIOB->PUPDR |= GPIO_PUPDR_PUPDR7_0 | GPIO_PUPDR_PUPDR8_0; // Enable Pull-Ups for PB7,8
	GPIOB->MODER |= GPIO_MODER_MODER7_1 | GPIO_MODER_MODER8_1;
	GPIOB->AFR[0] |= (4 << 28); // AF4 for PB7 SDA
	GPIOB->AFR[1] |= (4 << 0);  // AF4 for PB8 SCL
	I2C1->OAR1 = (0x09 << 1) | (1 << 14);
	NVIC_EnableIRQ(I2C1_EV_IRQn); // Enable I2C1 EV IRQ
	NVIC_EnableIRQ(I2C1_ER_IRQn); // Enable I2C1 ER IRQ
	I2C1->CR2 |= I2C_CR2_ITERREN | I2C_CR2_ITEVTEN | I2C_CR2_ITBUFEN; 
	I2C1->CR1 |= I2C_CR1_ACK | I2C_CR1_PE;

	i2c_reg_idx = 0;
	i2c_bytes_received = 0;
}


void I2C1_EV_IRQHandler() 
{
	uint16_t temp;
	uint16_t stat1 = 0;
	//uint16_t stat2 = 0;
	uint32_t data;

	stat1 = I2C1->SR1;
	//stat2 = I2C1->SR2;

	if(stat1 & I2C_SR1_ADDR) // ADDR matched, EV1
	{
		temp = I2C1->SR1;
		temp = I2C1->SR2;
		i2c_bytes_received = 0;
	}
	
	if(stat1 & I2C_SR1_RXNE) // Recv. reg. not empty EV2
	{		
		data = I2C1->DR;
		i2c_bytes_received++;
		if(i2c_bytes_received == 1)
			i2c_reg_idx = data;
		else
			i2c_regs[i2c_reg_idx] = data;
	}
	
	if(stat1 & I2C_SR1_TXE) // Transm. reg. empty
	{	
		I2C1->DR = i2c_regs[i2c_reg_idx];
	}	
	
	if(stat1 & I2C_SR1_BTF) // Byte Transfer Finished
	{
		LED(ORANGE, 1);
	}
	
	if(stat1 & I2C_SR1_STOPF) // STOP received, EV4
	{
		// clear this flag
		temp = I2C1->SR1;
		I2C1->CR1 |= I2C_CR1_PE;
	}
}

void I2C1_ER_IRQHandler() 
{
	uint16_t stat1 = 0;
	//uint16_t stat2 = 0;

	stat1 = I2C1->SR1;
	//stat2 = I2C1->SR2;

	LED(RED, 1);
	
	if(stat1 & I2C_SR1_AF) // ACK failure (NACK)
	{
		I2C1->SR1 &= ~I2C_SR1_AF;
		LED(RED, 0);
	}
	
	if(stat1 & I2C_SR1_OVR) // Overflow
	{
		I2C1->SR1 &= ~I2C_SR1_OVR;
		LED(RED, 0);
	}
}

void wait(uint32_t nCount)
{
  while(nCount--)
  {
	  __asm__("NOP");
  }
}

int main(void)
{
	int i = 100;

	init_leds();
	init_usart();
	init_printf(NULL, putc);
	//init_timer3();
	//init_i2c();
	printf("Hello %d \n", i);
	printf("ala ma kota\n");
	while(1) {
		wait(6000000);
	}
}

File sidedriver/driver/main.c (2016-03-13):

/* wojtekbe@gmaill.com */
#include "stm32f4xx.h"
#include "core_cm4.h"
#include <unistd.h>
#include <math.h>
#include "debug.h"
#include "time.h"
#include "motordriver.h"
#include "tankdriver.h"
#include "extio.h"
#include "regs.h"

void _wait(uint32_t);
int update_conf(void);

#define VECT_SIZE 5000
int32_t vect[VECT_SIZE];
int32_t vect2[VECT_SIZE];
int i;
int r;

void _wait(uint32_t nCount)
{
	while(nCount--)
		__asm__("NOP");
}

int update_conf(void)
{
	md_w_ref = (regs[M_SET_SPEED] | (regs[M_SET_SPEED + 1] << 8));
	// TODO store md_w
	regs[M_SPEED + 1] = (md_w >> 8) & 0x0FF;
	regs[M_SPEED] = md_w & 0x0FF;

	regs_print();

	//md_set_speed(md_w_ref); // with PID disabled
	td_set_pos((regs[TANK_SET_POS] | (regs[TANK_SET_POS + 1] << 8)));

	// TODO store td_cpos
	return 0;
}

int main(void)
{

	debug_init(); /* on USART1 */
	//debug("hello %d\n", (int)SystemCoreClock);

	//time_init();

	i2c_init(); /* I2C1 */

	td_init();
	td_enable();

	md_init();
	md_enable();

	//extio_init();
	//r = 1;
	//i = 0;

	while(1)
	{
		//i2c_print_regs();
		update_conf();
		//debug("PID: x = %d, x_r = %d, u = %d\n", (int)*pid.x, (int)*pid.x_ref, pid.u);

		//debug("%d: ADC3 = %d g\n", time_ms, extio_adc1_read()/4);

		//if (r) {
		//	debug("%d\t%d\t%d\t%d\n", i, md_w, md_w_ref, pid.u);
		// debug("%d	%d	%d	%d\n", i, (int32_t)TIM8->CNT, (int32_t)md_lpos, md_w);
		// i++;
		_wait(10000000);
	}
}

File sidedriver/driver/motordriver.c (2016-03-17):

/* wojtekbe@gmaill.com */
#include <stdlib.h>
#include "stm32f4xx.h"
#include "core_cm4.h"
#include "debug.h"
#include "motordriver.h"
#include "regs.h"

#define PID_MAX_U 3370
#define PID_DEADZONE_WIDTH 350
#define M1_MAX_SPEED 3370

void pid_init(void);
void TIM4_IRQHandler(void); /* Calculate speed isr */
void TIM5_IRQHandler(void); /* PID isr */

int md_enc_upd_ms;

void md_init(void)
{
	/*
	 * M1-PWM 	PA1 	TIM2_CH2
	 * M1-CS 	PA2 	ADC123_IN2
	 * M1-ENB 	PA0 	out
	 * M1-INB 	PA4 	out
	 * M1-INA 	PC2 	out
	 * M1-ENA 	PC3 	out
	 * ENC1 	PC6 	TIM8_CH1
	 * ENC2 	PC7 	TIM8_CH2
	 *
	 * TIM2     PWM
	 * TIM4     calculate speed isr
	 * TIM5     PID isr
	 * TIM8     encoder
	 */

	//debug("#md_init()\n");

	/* IOs */
	RCC->AHB1ENR |= RCC_AHB1ENR_GPIOAEN;
	GPIOA->MODER |= GPIO_MODER_MODER0_0; // M1-ENB
	GPIOA->MODER |= GPIO_MODER_MODER4_0; // M1-INB
	RCC->AHB1ENR |= RCC_AHB1ENR_GPIOCEN;
	GPIOC->MODER |= GPIO_MODER_MODER2_0; // M1-INA
	GPIOC->MODER |= GPIO_MODER_MODER3_0; // M1-ENA

	/* PWM: TIM2_CH2 (PA1/AF1) */
	GPIOA->MODER |= GPIO_MODER_MODER1_1; // AF
	GPIOA->AFR[0] |= (1 << 4); // AF1
	RCC->APB1ENR |= RCC_APB1ENR_TIM2EN;
	TIM2->PSC =   83;
	TIM2->ARR =   99; // 10 kHz
	TIM2->CCMR1 = TIM_CCMR1_OC2M_2 | TIM_CCMR1_OC2M_1;
	TIM2->CCER = TIM_CCER_CC2E;

	/* Encoder: counting tics: TIM8_CH1/2 (PC6/7 AF3) */
	GPIOC->MODER |= GPIO_MODER_MODER6_1; // PC6 -> AF
	GPIOC->AFR[0] |= (3 << 24); // PC6 -> AF3
	GPIOC->MODER |= GPIO_MODER_MODER7_1; // PC7 -> AF
	GPIOC->AFR[0] |= (3 << 28); // PC7 -> AF3
	RCC->APB2ENR |= RCC_APB2ENR_TIM8EN;
	TIM8->ARR = 0xFFFF;
	TIM8->PSC = 2 - 1; // (Prescaler - 1)
	TIM8->CCMR1 = TIM_CCMR1_CC1S_0 | TIM_CCMR1_CC2S_0; // CC1S = 01, CC2S = 02 (inputs)
	TIM8->CCER |= TIM_CCER_CC1P | TIM_CCER_CC2P; // CC1P = 1, CC2P = 1 input polarity
	TIM8->SMCR |= TIM_SMCR_SMS_1 | TIM_SMCR_SMS_0; // Slave Mode, SMS = 011, Encoder Mode 3 p. 615
	TIM8->EGR |= TIM_EGR_UG; /* Force update */
	TIM8->CR1 |= TIM_CR1_CEN;
	TIM8->SR &= ~0x1; /* Clear update flag */

	/* Calculate speed using TIM4 interrupt */
	RCC->APB1ENR |= RCC_APB1ENR_TIM4EN;
	TIM4->PSC = 8400 - 1;
	TIM4->ARR = 200 - 1;
	TIM4->DIER = TIM_DIER_UIE;
	NVIC_EnableIRQ(TIM4_IRQn);
	TIM4->EGR |= TIM_EGR_UG; /* Force update */
	TIM4->CR1 |= TIM_CR1_CEN;
	md_enc_upd_ms = ( ((TIM4->PSC+1)*(TIM4->ARR+1)) / 84000 );

	md_cpos = 0;
	md_lpos = 0;
	md_w = 0;
	md_w_ref = 0;

	/* TODO Current measure: M1-CS */

	/* define PID inputs, init PID */
	pid.x = &md_w;
	pid.x_ref = &md_w_ref;
	pid.Kp = &regs[PID_KP];
	pid.Ki = &regs[PID_KI];
	pid.Kd = &regs[PID_KD];
	pid_init();

	debug("#md_init OK\n");
}

void TIM4_IRQHandler(void)  /* Encoder IRQ */
{
	if(TIM4->SR & TIM_SR_UIF)
	{
		md_cpos = TIM8->CNT;

		if (TIM8->SR & 0x01) { // counter overflow/underflow
			md_w = (int16_t)(md_cpos + 0xFFFF - md_lpos) * 30 / 4; /* [RPM] */
			TIM8->SR &= ~0x01;
		}
		else
			md_w = (int16_t)(md_cpos - md_lpos) * 30 / 4; /* [RPM] */

		md_lpos = md_cpos;
	}
	TIM4->SR &= ~TIM_SR_UIF;
}

void md_set_speed(int16_t w)
{
	uint16_t pwm;

	//debug("%s(%d)\n", __func__, w);

	if (w > M1_MAX_SPEED)
		w = M1_MAX_SPEED;

	if (w < -M1_MAX_SPEED)
		w = -M1_MAX_SPEED;

	pwm = (abs(w) * (TIM2->ARR + 1) / M1_MAX_SPEED);

	if (w == 0) {
		TIM2->CR1 &= ~TIM_CR1_CEN; // stop counting/pwm
		TIM2->CCR2 = 0;
	} else if (w > 0) {
		TIM2->CCR2 = pwm;
		TIM2->CR1 |= TIM_CR1_CEN; // pwm start
		GPIOC->ODR |=  (1 << 2); // M1-INA = 1
		GPIOA->ODR &= ~(1 << 4); // M1-INB = 0
	} else {
		TIM2->CCR2 = pwm;
		TIM2->CR1 |= TIM_CR1_CEN; // pwm start
		GPIOC->ODR &= ~(1 << 2); // M1-INA = 0
		GPIOA->ODR |=  (1 << 4); // M1-INB = 1
	}
}

void pid_init(void)
{
	RCC->APB1ENR |= RCC_APB1ENR_TIM5EN;
	TIM5->PSC = 8400 - 1;
	TIM5->ARR = 2000 - 1;
	TIM5->DIER = TIM_DIER_UIE;
	NVIC_EnableIRQ(TIM5_IRQn);
	TIM5->CR1 |= TIM_CR1_CEN; // PID start

	*(pid.Kp) = 2; /* Kp/10 */
	*(pid.Ki) = 400;
	*(pid.Kd) = 1;

	pid.Tp = (((TIM5->PSC+1)*(TIM5->ARR+1)) / 84000); // in ms
	pid.last_e = 0;
	pid.sum_of_e = 0;
	pid.enabled = 1;

	debug("#motord: pid_init OK\n");
}

void TIM5_IRQHandler(void) /* PID IRQ */
{
	if(TIM5->SR & TIM_SR_UIF) {
		pid.e = *pid.x_ref - *pid.x;
		pid.sum_of_e += pid.e;

		pid.u = *(pid.Kp) * (
				pid.e +
				(pid.Tp * pid.sum_of_e / *(pid.Ki)) +  /* integr. */
				(*(pid.Kd) * (pid.e - pid.last_e) / pid.Tp) /* diff */
				) / 10;

		/* limit u */
		if (pid.u > PID_MAX_U)
			pid.u = PID_MAX_U;
		if (pid.u < -PID_MAX_U)
			pid.u = -PID_MAX_U;

		/* deadzone */
		if ((pid.u > 0) && (pid.u < PID_DEADZONE_WIDTH))
			pid.u = 0;
		if ((pid.u < 0) && (pid.u > -PID_DEADZONE_WIDTH))
			pid.u = 0;

		pid.last_e = pid.e;

		/* set the speed */
		md_set_speed(pid.u);
	}
	TIM5->SR &= ~TIM_SR_UIF;

}

void md_enable()
{
	// debug("md_enable()\n");

	GPIOC->ODR |= (1 << 3); // M1-ENA = 1
	GPIOA->ODR |= (1 << 0); // M1-ENB = 1
}

void md_disable()
{
	//debug("md_disable()\n");

	GPIOC->ODR &= ~(1 << 3); // M1-ENA = 0
	GPIOA->ODR &= ~(1 << 0); // M1-ENB = 0
}

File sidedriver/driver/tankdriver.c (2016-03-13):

/* wojtekbe@gmaill.com */
#include "stm32f4xx.h"
#include "core_cm4.h"
#include "tankdriver.h"
#include <debug.h>


/* private */
void TIM1_BRK_TIM9_IRQHandler(void);
void td_set_pwm(uint32_t);
extern void _wait(uint32_t nCount);

void td_init()
{
	/*
	 * M2-PWM 	PB0 	TIM1_CH2N
	 * M2-ENA 	PB1 	out
	 * M2-INA 	PB2 	out
	 * MIN		PB10	in
	 * MAX		PB11	in
	 * M2-ENB 	PA6 	out
	 * M2-INB 	PA5 	out
	 * TRANS 	PA3 	TIM9_CH2
	 *
	 * TIM1     PWM
	 * TIM9     TRANSOPT.
	 */

	/* IOs */
	RCC->AHB1ENR |= RCC_AHB1ENR_GPIOBEN;
	GPIOB->MODER |= GPIO_MODER_MODER1_0; /* M2-ENA */
	GPIOB->MODER |= GPIO_MODER_MODER2_0; /* M2-INA */

	RCC->AHB1ENR |= RCC_AHB1ENR_GPIOAEN;
	GPIOA->MODER |= GPIO_MODER_MODER6_0; /* M2-ENB */
	GPIOA->MODER |= GPIO_MODER_MODER5_0; /* M2-INB */

	/* MIN MAX */
	RCC->AHB1ENR |= RCC_AHB1ENR_GPIOBEN;
	GPIOB->PUPDR |= (1 << 21) | (1 << 23);

	//RCC->APB2ENR |= RCC_APB2ENR_SYSCFGEN;
	//SYSCFG->EXTICR[2] |= (1 << 12);  /* MAX */
	//SYSCFG->EXTICR[2] |= (1 << 8); // PB10
	//EXTI->IMR |= (1 << 11); // Interrupt Mask Reg.
	//EXTI->FTSR |= (1 << 11); // MAX Falling Trigger
	//NVIC_EnableIRQ(EXTI15_10_IRQn);



	/* PWM: TIM1_CH2N (PB0/AF1) */
	GPIOB->MODER |= GPIO_MODER_MODER0_1; // AF
	GPIOB->AFR[0] |= (1 << 0); // AF1
	RCC->APB2ENR |= RCC_APB2ENR_TIM1EN;
	TIM1->PSC =   10 - 1;
	TIM1->ARR =   100 - 1;
	TIM1->BDTR |= TIM_BDTR_MOE;
	TIM1->CCMR1 = TIM_CCMR1_OC2M_2 | TIM_CCMR1_OC2M_1; // PWM mode for CH2
	TIM1->CCER = TIM_CCER_CC2NE;

	td_reset();

	/* TRANSOPT. TIM9_CH2 (PA3/AF3) */
	/* generate interrupt on falling edge on PA3 */
	RCC->AHB1ENR |= RCC_AHB1ENR_GPIOAEN;
	GPIOA->MODER |= GPIO_MODER_MODER3_1; // AF
	GPIOA->AFR[0] |= (0x03 << (4 * 3)); // AF3
	NVIC_EnableIRQ(TIM1_BRK_TIM9_IRQn);
	RCC->APB2ENR |= RCC_APB2ENR_TIM9EN;
	TIM9->PSC = 0;
	TIM9->ARR = 0xFFFF - 1;
	TIM9->CCMR1 |= TIM_CCMR1_CC2S_0 | TIM_CCMR1_IC2F_2; /* input capture on chann. 3, filter */
	TIM9->CCER |= TIM_CCER_CC2E | TIM_CCER_CC2P; /* Enable input chann. 3, detect falling edges */
	TIM9->DIER |= TIM_DIER_CC2IE; /* Enable interrupt */
	TIM9->CR1 |= TIM_CR1_CEN;
	TIM9->EGR |= TIM_EGR_UG; /* Force update */

	td_is_at_max = 0;
	td_pos = 0;
	td_cpos = 0;
	td_set_dir(0);

	debug("#td_init OK\n");
}

void TIM1_BRK_TIM9_IRQHandler(void)  /* Transoptor IRQ */
{
	LEDT();
	if(TIM9->SR & TIM_SR_CC2IF) {
		td_cpos += td_dir;
		//debug("%d %d %d %x\n", (int)td_pos, (int)td_cpos, (int)td_dir, ((GPIOB->IDR & (1 << 10)) ? 1 : 0));
		if (MIN == 0)
			td_cpos = 0;

		if (td_cpos == td_pos)
			td_set_dir(0);

		// check if we reached MAX while going "up"
		if (((GPIOB->IDR & (1 << 11)) == 0) && (td_dir == WATER_IN)) {
			td_is_at_max = 1;
			td_set_dir(0);
		}
		else {
			td_is_at_max = 0;
		}

		TIM9->SR &= ~TIM_SR_CC2IF;
	}
}

void td_set_pos(int p)
{
	//debug("td_set_pos()\n");
	int dpos = p - td_cpos;
	td_pos = p;
	if (dpos < 0) {
		td_set_pwm(TANK_SPEED);
		td_set_dir(dpos);
	}
	// stop if we try to go further than MAX
	if (dpos > 0 && (td_is_at_max == 0)) {
		td_set_pwm(TANK_SPEED);
		td_set_dir(dpos);
	}
}

int td_tank_is_ready()
{
	int i;
	int ret = 0;
	int max_tries = 50;

	for(i = 0; i < max_tries; i++) {
		if((GPIOB->IDR & (1 << 10)) == 0) {
			ret++;
		}
		_wait(100);
	}

	if(ret == max_tries) {
		ret = 1;
	}
	else {
		ret = 0;
	}

	return ret;

}

void td_reset()
{
	td_enable();
	td_set_dir(WATER_OUT);
	td_set_pwm(TANK_SPEED);

	while(td_tank_is_ready() == 0);

	td_set_pwm(0);
	td_set_dir(0);
	td_disable();
}

void td_set_pwm(uint32_t width)
{
	if(width != TIM1->CCR2)
	{
		if(width == 0)
			TIM1->CR1 &= ~TIM_CR1_CEN;
		else
			TIM1->CR1 |= TIM_CR1_CEN;

		TIM1->CCR2 = width;
	}
}

void td_enable()
{
	GPIOB->ODR |= (1 << 1); // M2-ENA = 1
	GPIOA->ODR |= (1 << 6); // M2-ENB = 1
}

void td_disable()
{
	//debug("td_disable()\n");
	GPIOB->ODR &= ~(1 << 1); // M2-ENA = 0
	GPIOA->ODR &= ~(1 << 6); // M2-ENB = 0
}

void td_set_dir(int32_t d)
{
	if (d == 0) {
		td_dir = 0;
		GPIOB->ODR &= ~(1 << 2); // M2-INA = 0
		GPIOA->ODR &= ~(1 << 5); // M2-INB = 0
	}
	else if(d < 0) { // water out
		td_dir = WATER_OUT;
		GPIOB->ODR |=  (1 << 2); // M2-INA = 1
		GPIOA->ODR &= ~(1 << 5); // M2-INB = 0
	}
	else { // water in
		td_dir = WATER_IN;
		GPIOB->ODR &= ~(1 << 2); // M2-INA = 0
		GPIOA->ODR |=  (1 << 5); // M2-INB = 1
	}
}

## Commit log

2013-11-20 libs added, single mainboard (again)
    [i2-mb_rpi_s.brd, i2-mb_rpi_s.sch]
2013-11-20 i2 sidedriver added
    [sidedriver_v1.brd, sidedriver_v1.sch]
2013-11-20 zmieniony ksztalt mainb
    [i2-mb_rpi_s.brd, i2-mb_rpi_s.sch, mainb-dim.dwg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]
2013-11-20 20-11-13 21:08
    [i2-mb_rpi_s.brd, mainb-dim.dwg]
2013-11-21 21.11.13 23:39
    [i2-mb_rpi_s.brd, i2-mb_rpi_s.sch, sidedriver_v1.brd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]
2013-11-22 22.11.13 17:00
    [i2-mb_rpi_s.brd]
2013-11-26 26.11 10:46
    [LZ1.brd, LZ1.sch, LZ4.brd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]
2013-11-28 RPi camera board added and library, added servos.lbr
    [i2-mb_rpi_s.brd, i2-mb_rpi_s.sch, rpicam.brd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]
2013-12-03 03-12-13 20:52
    [i2-mb_rpi_s.brd, i2-mb_rpi_s.sch, rpicam.brd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]
2013-12-11 11.12.13 18:50
    [i2-mb_rpi_s.brd, i2-mb_rpi_s.sch, mainb-dim.dwg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]
2013-12-11 11.12.13 18:51
    [i2-mainb-dim.dwg]
2014-01-26 misc changes
    [i2-mb_rpi_s.brd, i2-mb_rpi_s.sch, rpicam.sch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]
2014-01-28 porzadki w mainb/
    [i2-hub.brd, i2-hub.sch, i2-mb_rpi.brd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]
2014-01-28 dodano docs/
    [chessboards.dwg]
2014-01-28 rm docs/
    [chessboards.dwg]
2014-01-28 /mainb: 1) pins on relays
    [i2-mb_rpi_s.brd, i2-mb_rpi_s.sch]
2014-01-28 mainb: 3) volt.reg. package dim.
    [i2-mb_rpi_s.brd, i2-mb_rpi_s.sch]
2014-01-28 mainb: 8) leds -> 3V3
    [i2-mb_rpi_s.brd, i2-mb_rpi_s.sch]
2014-01-28 mainb: 7) eth. conn. order
    [i2-mb_rpi_s.brd, i2-mb_rpi_s.sch]
2014-01-28 mainb: 9) battery holder wholes dia
    [i2-mb_rpi_s.brd, i2-mb_rpi_s.sch]
2014-01-28 mainb: 10) RPi UART for debugging
    [i2-mb_rpi_s.brd, i2-mb_rpi_s.sch]
2014-01-28 trinocular/rpicam/ added
    [i2-mb_rpi_s.brd, i2-mb_rpi_s.sch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]
2014-02-03 PWM on timer4, and USART2 on Discovery
    [b.gbl, bs.gbs, t.gtl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]
2014-02-04 fixed USART 0x12 issue
    [main.c]
2014-02-11 I2C working on Discovery
2014-02-11 rpicam: setup TWI, calibrated servo
2014-02-25 mainb rev. 2 added
    [i2-mb_rpi_s.brd, i2-mb_rpi_s.sch, ledd1.brd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]
2014-02-25 migrating from doscovery to sidedriv. board
2014-03-05 trinocular: added app to capture frames from fifo with Opencv
2014-03-08 sidedriver: ledd misc changes
2014-03-11 sidedrv: init funcs for drivers, misc changes
2014-03-11 sidedriver: rm readme.md, pin config in main.c
2014-03-12 sidedriver: i2c improvements in driver-discovery
2014-03-15 sidedriver: improved i2c on discovery
2014-03-15 siderdriver: added i2c support
2014-03-18 sidedriver: added support for counting encoder ticks, minor improvements
2014-03-19 sidedriver: stopped using STM32F4xx_StdPeriph_Driver, updated Makefile
2014-03-29 siderdriver: initial PID controller implementation
2014-03-29 sidedriver: added support for 2b i2c 'registers'
2014-04-09 sidedriver: PID contr. tests
2014-05-06 sidedriver: some improvements in PID controller
2014-05-11 sidedriver: PID controller tweaks
2014-05-13 mainb: mainb_v2 PCB created using kicad
    [mainb_v2.sch]
2014-05-14 mainb: mainb_v2 kicad schematic updates
    [mainb_v2.sch]
2014-05-14 mainb: kicad sch updates
    [mainb_v2.kicad_pcb, mainb_v2.sch]
2014-05-21 sidedriver: fixed a bug in calculating rot. speed (overflow/underflow)
    [main.c, motordriver.c]
2014-05-28 sidedriver: motordriver pid contr. updates
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2014-05-28 some updates in kicad project files, and some cleaning in sidedriver files
    [mainb_v2.kicad_pcb, mainb_v2.sch]
2014-06-04 sidedriver: resolved transoptor issue
    [tankdriver.c]
2014-06-08 KiCAD PCB project added
    [isfar2.kicad_pcb, isfar2.sch, mainb.kicad_pcb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]
2014-06-08 PCBs: PCB-kicad splitted
    [isfar2.kicad_pcb, isfar2.sch, mainb.kicad_pcb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]
2014-06-10 sidedriver: kicad pcb updates
    [sidedriver.sch]
2014-06-10 sidedriver: pid merged to motordriver
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2014-06-10 mainb: added tag for rev1, and provided updates
    [i2-mb.brd, i2-mb.sch, i2-mb_r1.brd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]
2014-06-10 sidedriver: Eagle pcb files ranamed
    [sidedriver.brd, sidedriver.sch]
2014-08-13 sidedriver: added ADC in external port
2014-08-13 sidedriver: PCB todo file added
2014-08-19 sidedriver: ADC calibrated to use with scale
2014-10-07 rpicam: rev2 PCB added
    [rpicam_rev2.brd, rpicam_rev2.sch]
2014-10-21 ledd: added some TODO comments to ledd1.sch
    [ledd1.sch]
2014-11-03 sidedriver: PCB rev.2 created
    [sidedriver.brd, sidedriver.sch]
2014-11-03 sidedriver: PCB rev.2 updates
    [sidedriver.brd, sidedriver.sch]
2014-12-12 rpicam: updated firmware to work with new PCB
2014-12-16 sidedriver: motordriver for rev.2
2015-04-08 sidedriver: 'make r' doesn't reset the board (compatible with stlink 79b413)
2015-04-08 sidedriver: fix compilation error in tankdriver.c
    [tankdriver.c]
2015-06-23 sidedriver: debug LED on PA12 support
2015-06-23 sidedriver: toggling debug LED with LEDT()
2015-07-07 sidedriver: tank resetting procedure
    [tankdriver.c]
2015-07-17 mainb: initial motor control (mctrl) and tank control (tctrl) scripts
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2015-12-03 sidedriver: add delay in td_reset(), change driving speed (PWM)
2015-12-10 sidedriver: tankdriver: td_reset() fix
    [tankdriver.c]
2015-12-12 sidedriver: doscovery: red LED turns on when in HardFault
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2016-03-09 mainb: script for switching dhcp to client mode
2016-03-12 sidedriver: printf() bug: debug() uses tinyprintf
    [debug.c, main.c, motordriver.c]
2016-03-13 siderdriver: PID: setting Kp, Ki, Kd via I2C
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2016-07-08 trinocular: rpicam hw revisions in single files
    [rpicam.brd, rpicam.sch, rpicam_rev2.brd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]
2016-07-08 trinocular: dir reorganized
    [rpicam.brd, rpicam.sch]
2016-07-08 trinocular: PCB rev.3 - wip
    [rpicam.brd, rpicam.sch]
2016-07-21 trinocular: PCB v3 - wip
    [rpicam.brd, rpicam.sch]
2016-08-11 trinocular: rpicam_v3 + gerbers
    [rpicam.brd, rpicam.sch]
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
